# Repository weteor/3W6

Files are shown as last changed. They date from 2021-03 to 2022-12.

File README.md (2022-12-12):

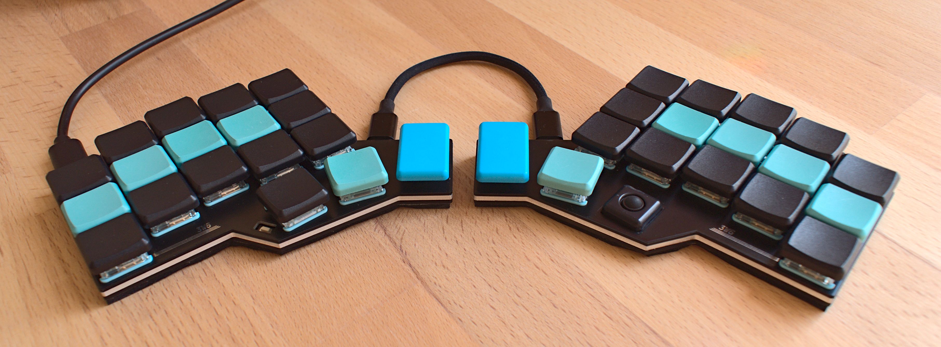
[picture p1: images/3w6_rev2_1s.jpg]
 

# 3w6 - split ortholinear keyboard

The 3w6 is a low profile, split ortholinear keyboard with 36 keys.

I needed a keyboard for work and wasn't really satisfied with the available alternatives (namely Corne, Kyria and Ferris), mostly because they were rather large and didn't had the spacing I would like.

It's designed to be a no frills, cheap and small keyboard to be taken everywhere.

So no hotswap, no multiple switchtypes, no encoders, no LEDs.

BUT with onboard controllers (so no extra ProMicros, Elite-C), production files including SMT assembly files, and sturdy through hole mounted USB-C connectors.
## revision 2.2
changes:
- combi footprint to be able to use the AU or MU variant of the AtMega32U4. 
- add BOM files for each AU and MU variant, so you can choose the cheaper one.
## revision 2
changes:
- new middle plate (1.6mm, better 2.0mm) instead of diodes. Uses Aluminium PCBs as a cheaper alternative to lasered aluminium. 
- pimoroni trackball support (can only be used combined with the new middle plate when used with the plate)
- plate is now 1.2mm thick, to fit the chocs better. Needs middle plate, since the cutouts of the USB-Connectors were left out. There is enough space for them under the plate, when the middle plate is in place.
- added mounting holes to support tenting puck from splitkb.com. Due to insufficient space not all 4 holes are supported, but 3 screws should be enough to hold everything comfortably in position. Can only be used plateless! 
- package for the MCU was changed from QFN44 to TQFP44, since the previous one wasn't available. Can now be soldered/replaced by hand if need.
- IO-expander was changed from TCA9555RTWR to TCA9555PWR (alternativly PCA9555PW), since the previous one wasn't available. Package changed from WQFN24 to TSSOP24. Can now be soldered/replaced by hand if need.
- Board can now be soldered by hand if needed (challenging though, 0402 components). 

## try it
You may also compare the layout with other layouts of other layouts at https://jhelvy.shinyapps.io/splitkbcompare/ .

Or you can print [this file](https://raw.githubusercontent.com/weteor/3W6/main/plate_outline.pdf) to test if you like the layout. Or mount it to some cardboard and test it with your favourite switches.

## production files
If you want to build one yourself, grab the 
Gerber files [here](https://github.com/weteor/3W6/tree/main/prod/Rev2) and give it a go.

And if 3d printing is your thing, files for plate and midlayer can be found [here](https://github.com/weteor/3W6/tree/main/prod/Rev2/3d%20Print) (made by the great [bomtarnes](https://github.com/keyboard-magpie), thanks a lot!)
## build instructions
you may find instructions here: 
- rev1 (deprecated): [build instructions rev1](./prod/build_instruction_rev1.md)
- **rev2 (current)**   : [build instructions rev2](./prod/build_instruction_rev2.md)

## firmware
This keyboard uses [QMK firmware](https://qmk.fm/).
You can find everything you need to build a firmware for this board in the [QMK Repository](https://github.com/qmk/qmk_firmware). 

Here are some instructions on how to [set up your QMK environment](https://docs.qmk.fm/#/newbs) and a few notes [specifically for the 3w6](https://github.com/qmk/qmk_firmware/tree/master/keyboards/3w6).

## the rest
Everything in this repository is free to use however you might see fit. If you want to support me and my projects, please consider linking back to this repository if you build/change/use anything. 

If you would like to send me a tip, you could do it [here](https://ko-fi.com/weteor) (Please don't feel like you have to).

## rev2(current)
3w6 
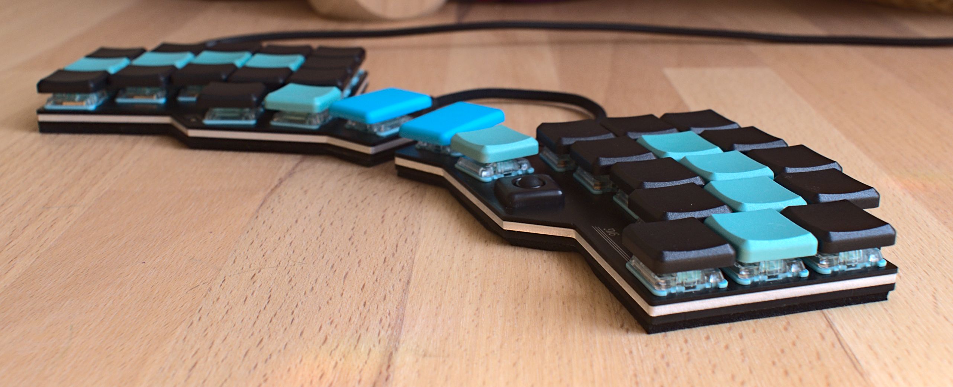
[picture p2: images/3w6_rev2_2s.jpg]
 
## rev1
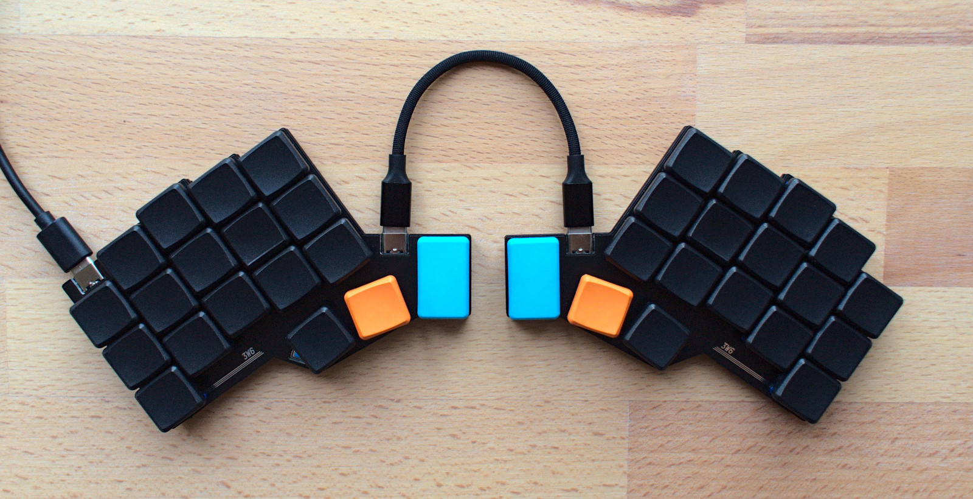
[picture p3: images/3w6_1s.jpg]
 
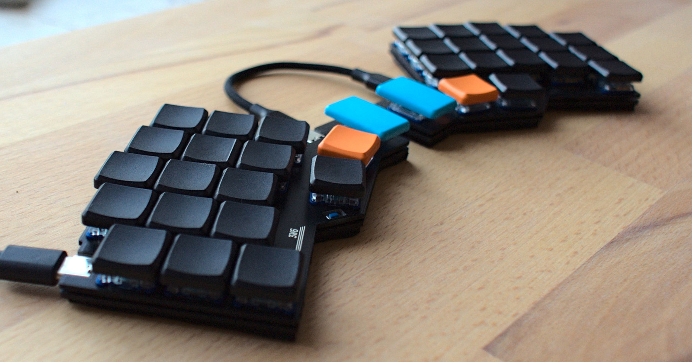
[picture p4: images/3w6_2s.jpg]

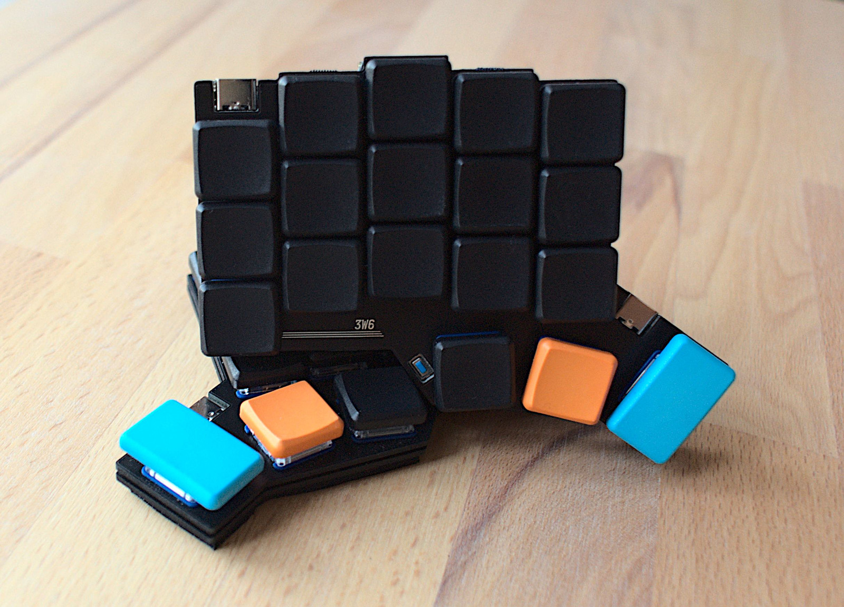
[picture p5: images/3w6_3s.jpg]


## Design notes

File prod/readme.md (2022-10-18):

# Build Guides
- [Build instructions for Rev1](./build_instruction_rev1.md) **outdated design**
- [Build instructinos for Rev2](./build_instruction_rev2.md)
- [Build instructions for Pimoroni on Rev2](./build_instruction_rev2_pimoroni.md)

# Production files
## Rev2 (current)
### Gerber

Prepared for JLCPCB, can be used everywhere, but BOM and placement files might be needing some adjustments)

| Component | Files | Description |
|---|---|---|
| PCB | 3W6_Pcb_Gerber_20221018.zip | Gerber PCB |
| -"- | 3W6_Pcb_PositionTop_20221018.csv | Position File for top Layer ( all smt components are on the top layer ) |
| -"- | 3W6_Pcb_BOM_20221018.csv | Bill of Materials w/ AtMega32U4-AU |
| -"- | 3W6_Pcb_BOM_20221018.csv | Bill of Materials |
| Mid Layer | 3W6_Middle_R_Gerber_20221018.zip | Gerber Middle Plate Right Half |
| -"- | 3W6_Middle_L_Gerber_20221018.zip | Gerber Middle Plate Left Half |
| Switch Plate | 3W6_Plate_Gerber_20221018.zip | Gerber Switch Plate |

### 3d printing files 
Files for mid layer and switchplate can be [found here](https://github.com/weteor/3W6/tree/main/prod/Rev2/3d%20Print)

Big thanks to [**bomtarnes**](https://github.com/keyboard-magpie) for making these files available

### Rev1 (outdated)

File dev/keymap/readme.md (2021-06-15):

###  Base Layer 

#### Colemak (default)
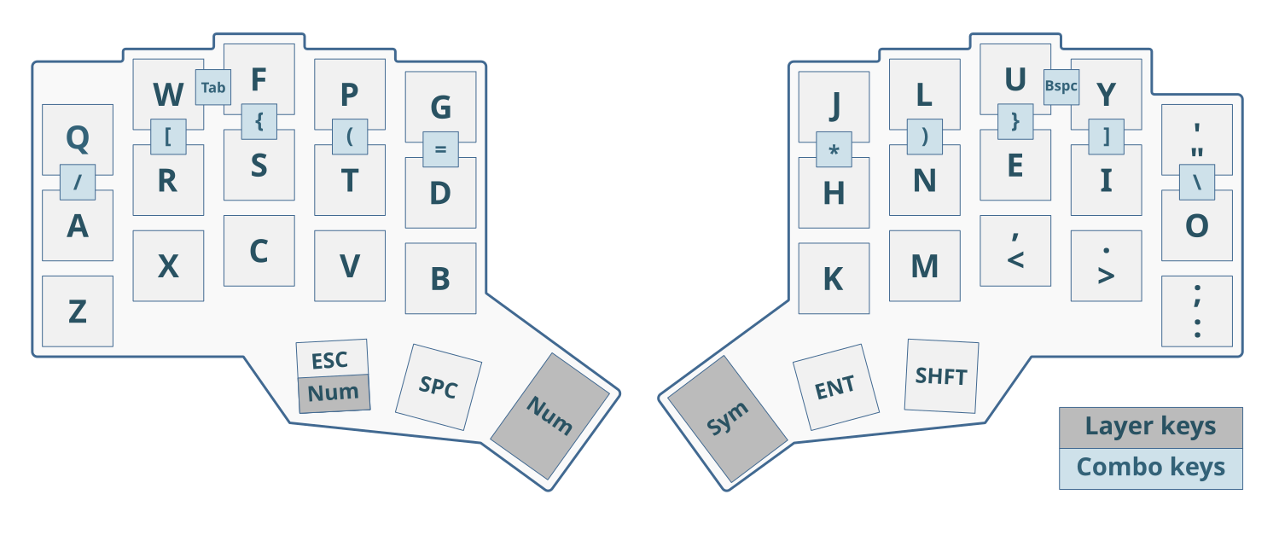
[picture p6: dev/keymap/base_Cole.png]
image colemak


#### Quertz
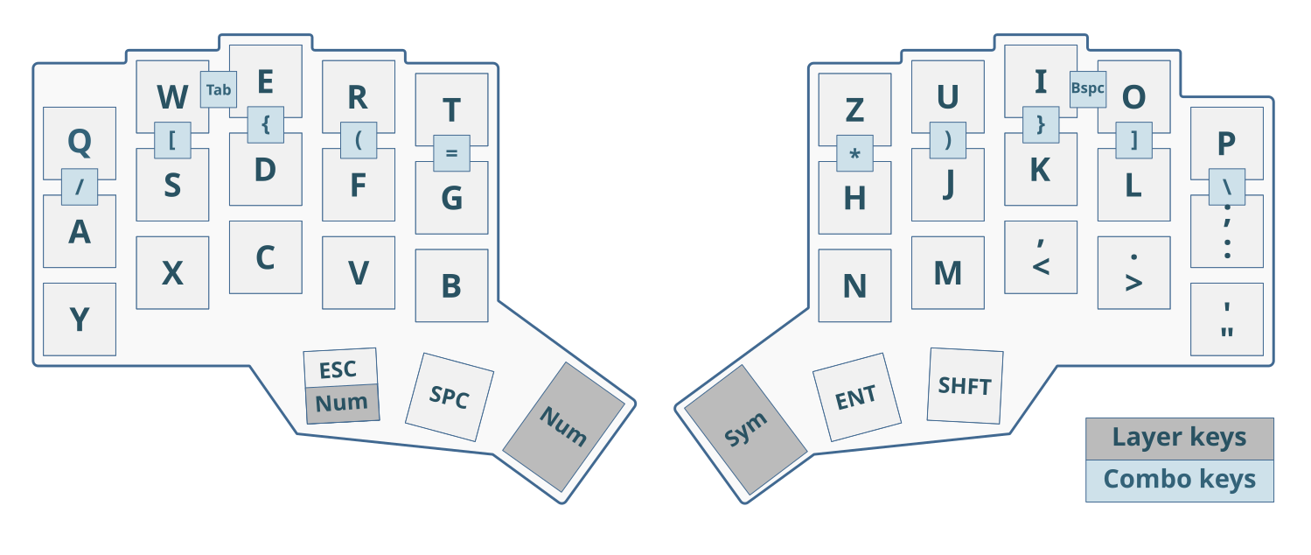
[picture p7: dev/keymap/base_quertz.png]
image quertz


#### Beakl, Colemak DH and Handsdown-Alt accessable through CFG Layer

### Symbol Layer
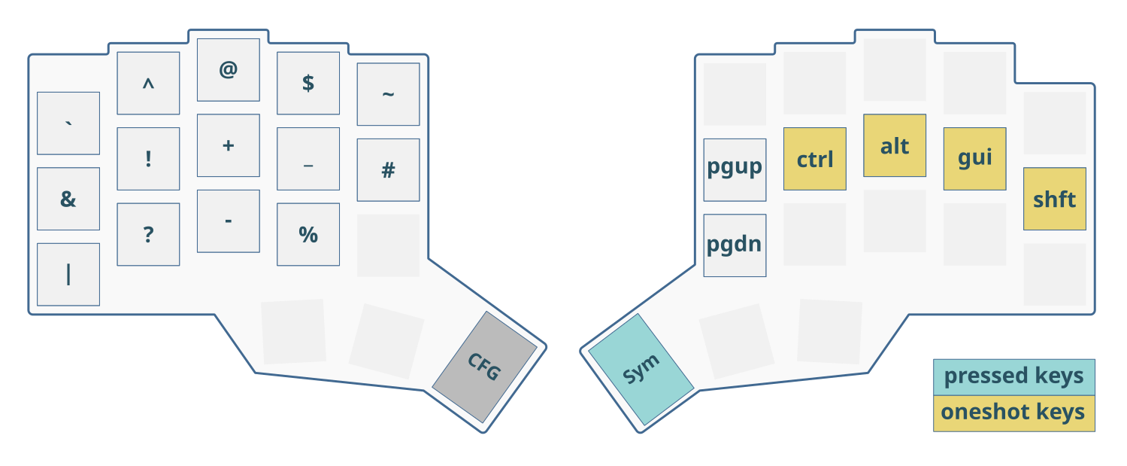
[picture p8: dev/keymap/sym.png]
image sym

 
### Navigation Layer
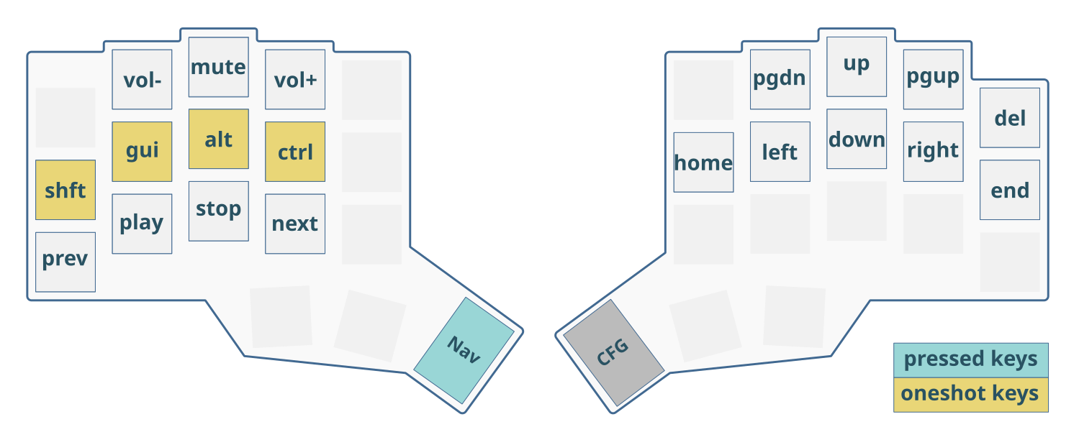
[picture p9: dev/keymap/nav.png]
image nav


### Number Layer
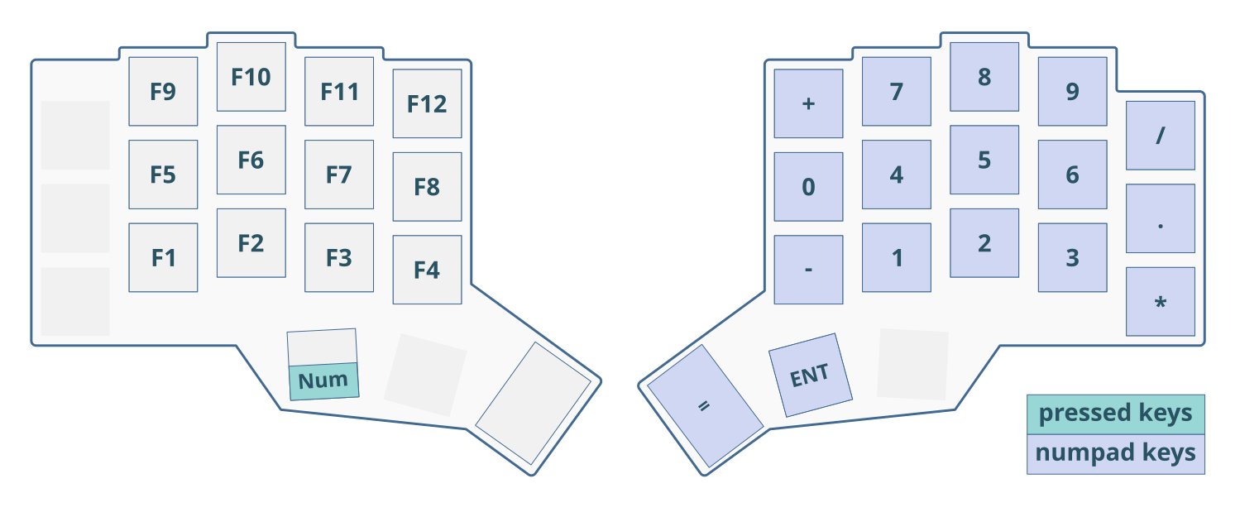
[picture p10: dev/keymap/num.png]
image num


### Config Layer
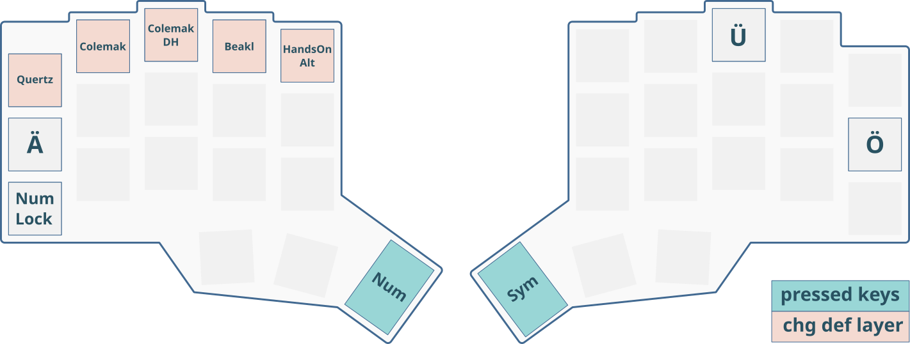
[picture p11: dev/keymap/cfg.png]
image cfg


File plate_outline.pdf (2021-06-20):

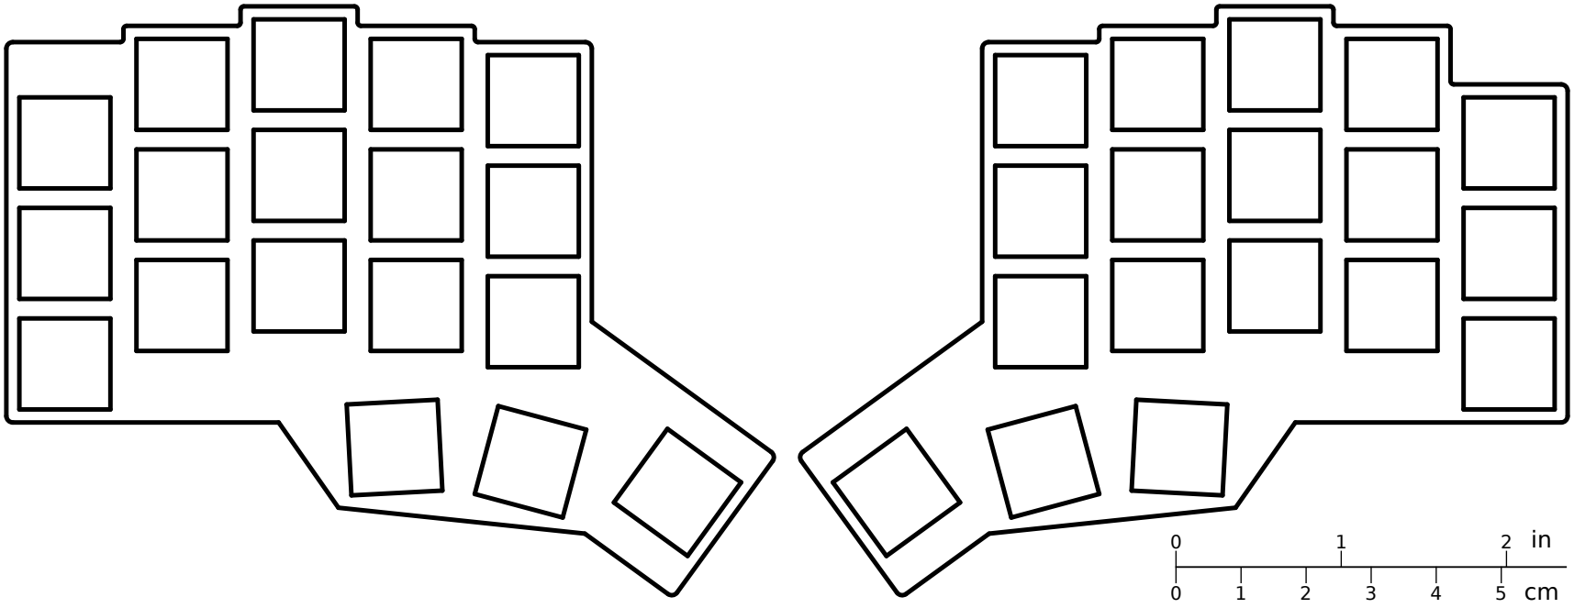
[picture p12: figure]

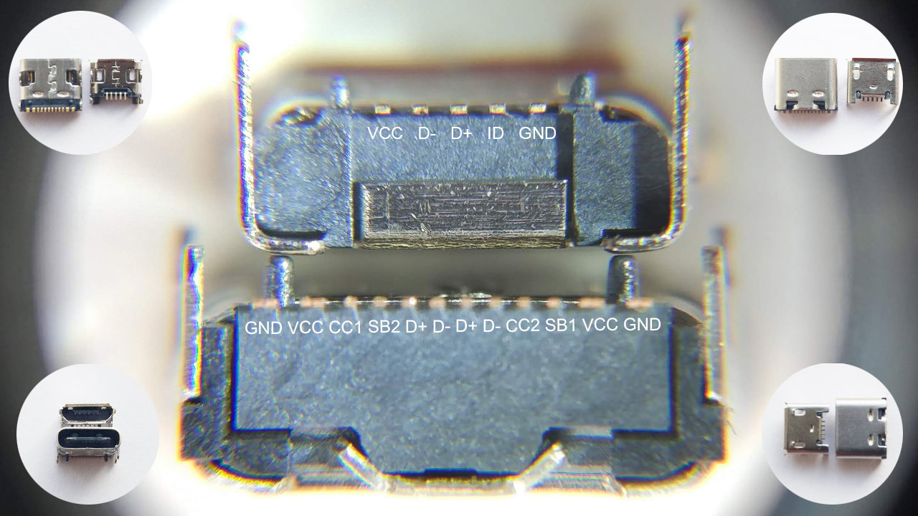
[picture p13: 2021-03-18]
dev/docs/USBC_12pin_Pinout.png

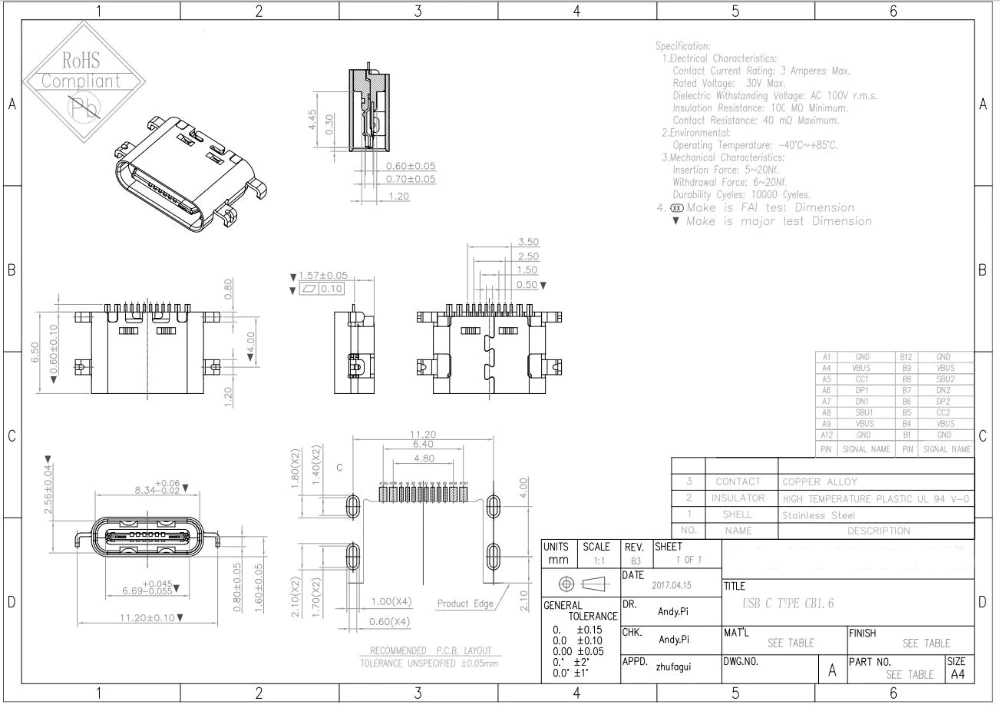
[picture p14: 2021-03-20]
dev/docs/USBC_12pin_DataSheet.png

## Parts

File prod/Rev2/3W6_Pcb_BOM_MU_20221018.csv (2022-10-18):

Comment | Designator | Footprint | LCSC
22pF | C1,C2 | Weteor:C_0402_HandSolder | C1555
0.1uF | C3,C4,C5,C6,C7 | Weteor:C_0402_HandSolder | C1525
4.7uF | C8 | Weteor:C_0402_HandSolder | C23733
1uF | C9 | Weteor:C_0402_HandSolder | C52923
D | D2,D3,D4,D5,D6,D7,D8,D9,D10,D11,D12,D13,D14,D15,D16,D17,D18,D19,D20,D21,D22,D23,D24,D25,D26,D27,D28,D29,D30,D31,D32,D33,D34,D35,D36,D37,D40,D43,D44,D50,D52 | Weteor:D_SOD-123 | C81598
500mA | F1 | Fuse:Fuse_1206_3216Metric | C106264
USB_C_midMount | J1, J2, J3 | Weteor:USB-C-12-Pin-MidMount | C168688
5.1k | R1,R2 | Weteor:R_0402_HandSolder | C25905
4.7k | R3,R4 | Weteor:R_0402_HandSolder | C25900
22R | R6,R7 | Weteor:R_0402_HandSolder | C25092
10k | R5,R8,R9 | Weteor:R_0402_HandSolder | C25744
ATmega32U4-AU | U1 | Package_QFP:TQFP-44_10x10mm_P0.8mm | C112161
PCA9555PW | U2 | Package_SO:TSSOP-24_4.4x7.8mm_P0.65mm | C128392
16MHZ | Y1 | Crystal:Crystal_SMD_3225-4Pin_3.2x2.5mm | C13738

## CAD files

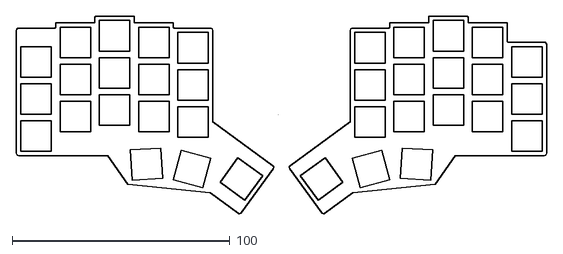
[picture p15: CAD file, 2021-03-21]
dev/Board Shape/OutlinePlate_v1.dxf
243.2 x 90.7

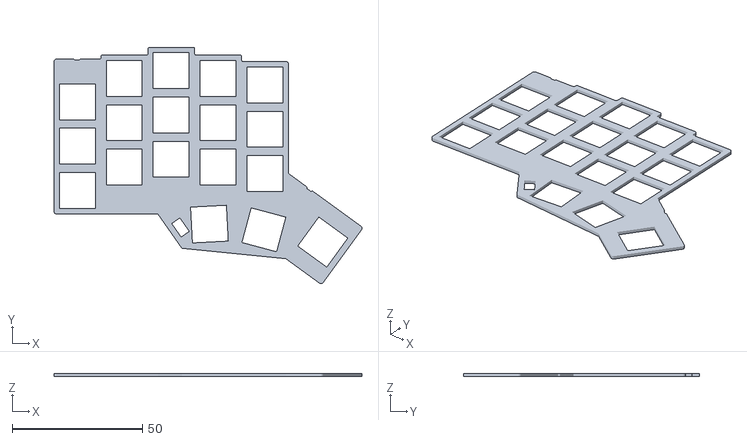
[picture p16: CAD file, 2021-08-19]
prod/Rev2/3d Print/3W6_Plate-left-v2.stl
118.2 x 90.7 x 1.20

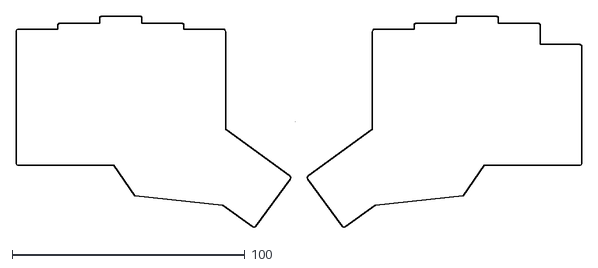
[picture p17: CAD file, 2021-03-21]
dev/Board Shape/Outline_v1.dxf
243.2 x 90.7

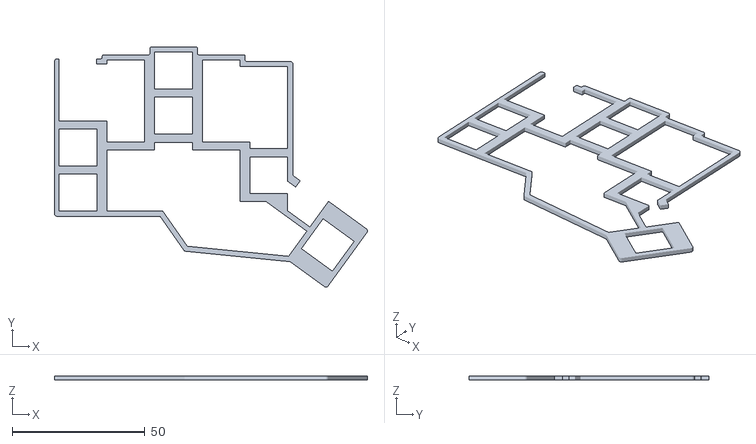
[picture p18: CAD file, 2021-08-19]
prod/Rev2/3d Print/3W6_Plate-middle-left-v2.stl
118.1 x 90.6 x 1.60

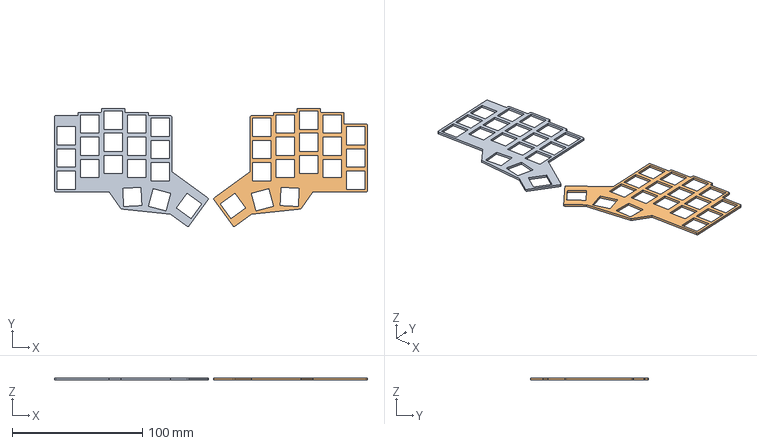
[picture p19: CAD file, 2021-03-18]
dev/Board Shape/Outline.FCStd
240.0 x 90.6 x 1.60 mm
Left Half
Pad001 (Mirror #1)

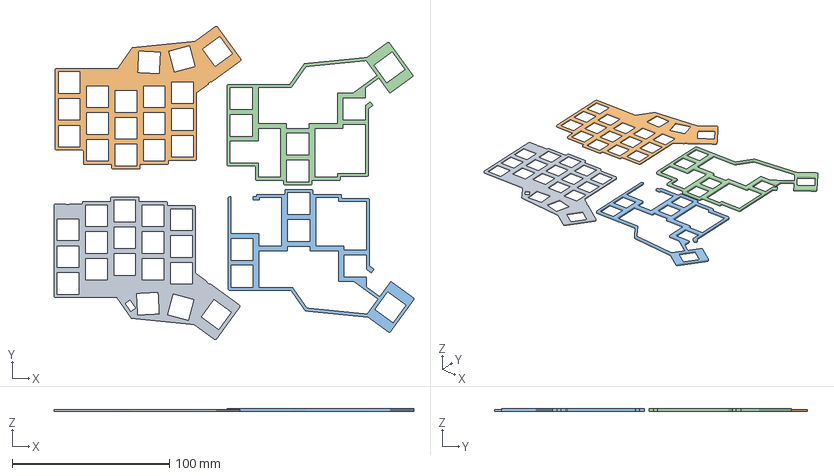
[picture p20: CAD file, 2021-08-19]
prod/Rev2/3d Print/3w6-prusa-plate-v2.3mf
228.7 x 199.1 x 1.60 mm
3W6_Plate-left-v2.stl
3W6_Plate-right-v2.stl
3W6_Plate-middle-left-v2.stl
3W6_Plate-middle-right-v2.stl

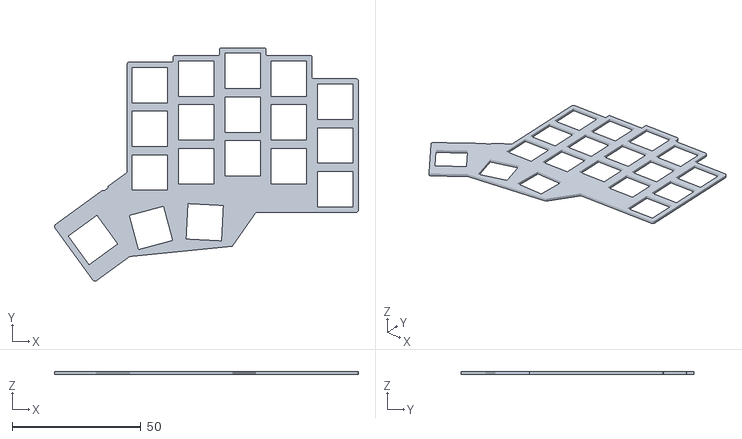
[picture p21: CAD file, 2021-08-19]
prod/Rev2/3d Print/3W6_Plate-right-v2.stl
118.2 x 90.7 x 1.20

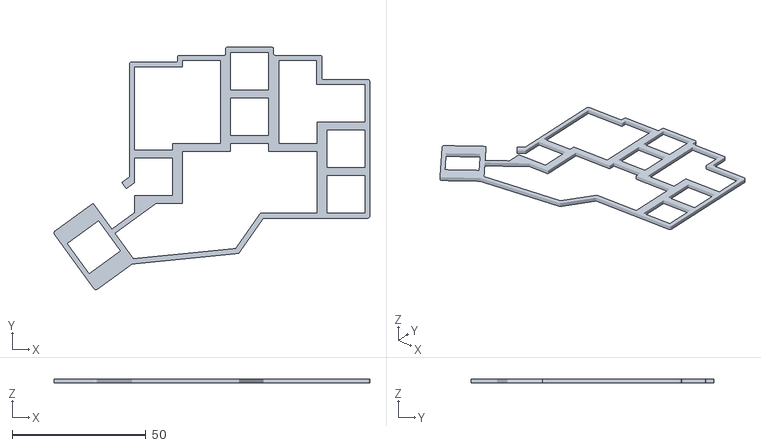
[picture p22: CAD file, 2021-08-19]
prod/Rev2/3d Print/3W6_Plate-middle-right-v2.stl
118.1 x 90.6 x 1.60

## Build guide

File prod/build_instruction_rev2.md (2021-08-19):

**if you are going to order pcb with the provided files please make sure the components in the BOM are still valid and have the correct values! I will update them from time to time, but there is no guarantee the current version is still correct.**

If the board was manufactured with the included Bom and Pick and Place Files the following components are needed to complete the build:

Amount | Component
-------|----------
1        | 3x6x2.5mm SMD Micro Switch, can be found on Ebay or Aliexpress
36       | Kailh Choc V1 switches
34       | Keycaps 1u, 17x18mm, Kailh original choc caps work, transparent ones might not. MKB fit perfectly
2        | Keycaps 1.5u, same as above exept size obviously
1        | USB-C to USB-A cable (connection to PC)
1        | USB-C to USB-C cable (connection between halves)
optional | [Pimoroni Trackball Breakout](https://shop.pimoroni.com/products/trackball-breakout)
optional | [Tenting Puck](https://splitkb.com/products/tenting-puck)
optional | some self adhesive neopren material to put under the board, *alternativly* some rubber feet
optional | black permanent marker to paint the edges of the PCB

optional step:
- use a black (or whatever color matches your board) permanent marker to paint all edges. I think it looks a lot nicer with darker edges.

ok, let's start:
- solder the microswitch. Start with one side and check if the plate will fit before soldering the other side.
- connect the left half ( the one with two USB connectors) to the PC and try to flash the board. 
- Open some kind of editor and check if the board is working by shorting the two slots for each switch on the bottom of the pcb (use a paperclip or tweezers). If single switches don't work check and/or change the matching diode.
- connect both sides and check the same way. ( you can safely connect the sides while the board is connected to the pc)

optional step:
- solder the pimoroni trackball to the pcb. [See instructions here](./build_instruction_rev2_pimoroni.md)

ok, ready to put the switches on.

- start with the six switches which are completely surrounded by the midlayer. Clip them in the plate and solder them to the pcb. If unsure solder just one leg, that way it is easier to correct mistakes. Make sure the middle plate is tightly squeezed between plate and pcb. If you use a 2mm midplate, it is normal that the switch pins are only barely visible on the back of the pcb.
- clip in a few more switches and solder them as above.
- rinse & repeat

optional step:
- cut the neopren to fit the board and tack it under it, or use some rubber feet. 

Congratulations, you should have a functioning and nice looking keyboard now!

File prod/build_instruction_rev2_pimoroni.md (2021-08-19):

**Build instructions for Pimoroni Trackball**

First we need to fit the trackball in the plate. The cutout is a tad too small to fit for the pimoroni to fit well with the choc switches.
Try to fit the trackball and use a file to widen the cutout untill the housing fits. File the edge nearest to the alpha keys.

Clip the six switches which are surrounded by the midplate into the plate.

Now we need to remove some parts of the pimoroni PCB ... don't panic, everything will be fine.
File away until the corner between the "5VOK" and "ADDR+1" print. 
This is how the result should look like:

Put the Pimoroni into the plate and try to fit it together with the midplate. The midplate should without being pushed out by the pimoroni pcb. If not, file a bit more until it fits.

ok, now take a look at the bottom of the pcb and see how the vias align between pcb and Pimoroni. There will be an overlap, thats ok. 
Solder some wire to each via on the Pimoroni. Try to keep the wire more to the edge. Try to fit the wires in a way that there is minimal wire or solder to the side where the plate will sit.

Again, fit the pimoroni in the plate. Use plate, switches and midplate to get a proper alignment and fit the wires through the pcb.

Solder and clip.

*if you use a Rev 2.0 board* (see back of pcb ner the inner thumbkey).
There is an error on the board. The Pomoroni GND PIN is not connected to the boards GND. Two options.

1. Solder a wire to the gnd pin. Feed it through the big hole next to the pimoroni and the IO Expander (the big chip) and solder the wire to the pins marked x (or look into the schematic to see which pins are gnd)
```
   | | | | | | | | | | | |
   | | | | | | | | | | | |
   -----------------------
  |                       |
  |       TCA9555         |
  |       TSSOP-24        |
   ------------------------
   | x x | | | | | | | | |
   | x x | | | | | | | | |
   
```
2. scrap away a bit of soldermask on the back of the board, the copperlayer there is Gnd. Either bridge with solder or use some wire to connect Pin with the copper.

Congratulations. Pimoroni installed!

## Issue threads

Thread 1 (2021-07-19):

Interested in getting one V2

llpamies, 2021-07-19:
I was trying to see if JLCPCB could make one, but they run out of TCA9535PWR...
Have you managed to order some V2? I am interested in buying a couple for myself. Thanks!

weteor, 2021-07-20:
Yeah, having all parts available is a problem right now. Changed the footprints of the IOExpander and the MUC because of that.
If you feel confident soldering and are able to source the TCA9535PWR from elsewhere, you could leave it out of the assembly and solder it on by yourself later.
If you don't want that, I have ordered a batch of 3W6 V2 and theoretically I still have 3 left over, so you can get one from me as well.
I will have to check the boards though. Last time I had a few duds and I must be sure  to have enough functioning boards. If you are interested let.me know and I come back to you, when I know how many boards I have left.

weteor, 2021-07-20:
Ok, so I messed up.

The TCA9535PWR isn't working. It has to be the TCA9555PWR. Same Chip, but the 9535 does not have  internal pullup resistors, which I missed when I swapped the chips. So the right half will not work.
Pinout is the same, you only need to change the Chip and JLCPCB Part number in the BOM File.
If the TI Version isn't available you could use the NXP PCA9555 which seems to be the same chip and it looks like it is in stock at JLCPCB at the moment.

llpamies, 2021-08-06:
Thanks. I have finally ordered 5 of the v2.1 They didn't have the microcontroller in stock, which I will have to solder manually. I only got PCBs, since I am planning to 3d print plates and case. If the boards work, I could sell 3 of them if anyone is interested.

weteor, 2021-08-15:
great, let me know if everything worked out

llpamies, 2021-08-19:
The build went perfect. Some notes:

- JLCPCB didn't have the MCU, so I had to desolder if from a Pro Micro I had lying around (with a big hot air gun).
- I didn't use the PCB plates in your production files, but I designed a single top-middle plate combo on onshape, and 3d printed it: https://tinyurl.com/w6n2rknr (you can export .stl via export, when you right click on the part list).
- I used sticky neoprene adhesive for the bottom plate.

Some pics (waiting on a shorter usb-c cable): https://photos.app.goo.gl/o8Fyw2KQMJSpyTG76

Thank you so much for sharing the design!!! It is the perfect keyboard for me!

Do you mind if I share the pics on r/ErgoMechKeyboards and link to your github?

weteor, 2021-08-19:
That's so great to hear.

Those boards look great, thanks for sharing the pics. And sure post/share wherever you like.

Yeah the MCU is a gamble. They are regularly oos. At least with v2 there is the possibility to solder them on yourself :)
I use the same sticky neoprene, its really nice. Everything stays where it belongs.

Hope you'll enjoy using the keyboard!

Closed 2021-08-15.

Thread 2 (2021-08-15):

Alternative MCU Packages

peterlok27, 2021-08-15:
Hi! Thank you for your effort. I love the design idea. Can I just ask whether the QFN-44 is compatible with the PCB? TQFN-44 is rather hard to find where I'm at :((

weteor, 2021-08-15:
Hi

unfortunately the QFN-44 is not compatible with Rev2. It hat to be the TQFP package.

I've just checked and LCSC has them in stock and they deliver almost everywhere. Maybe that is an option?

You may also check Octoparts, which lists stock on a multitude of sites, maybe you can find something there:
https://octopart.com/search?q=atmega32u4-au&currency=USD&specs=0

Closed 2021-08-24.

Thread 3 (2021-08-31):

Planning on ordering from JLCPCB, need some guidance

coniel, 2021-08-31:
First of all, thanks for the great work. The keyboard looks excellent. I've never ordered a PCB before so I was hopping to get some assistance.

JLCPCB seems to be out of three components:
- TCA9555PWR (they don't have NXP PCA9555PW either)
- ATMEGA32U4-AU
- 500mA fuse

I Think that I should be able to source and solder the TCA9555PWR and ATMEGA32U4-AU. I'm just wondering about the fuse, should be easy enough to find, but it looks tiny and I'm not sure I'd be able to solder it. Is there another model I could replace it with on JLCPCB?

I also have a few questions regarding the order process itself:
1. The SMT assembly should be on top, right?
2. On the Upload BOM/CPL screen, should I upload `3W6_Pcb_PositionTop_20210728.csv` as the CPL file?
3. The middle and plate should use aluminium as the base layer, right?
4. For the middle boards, it's asking for their dimensions. I'm not sure what to enter for that.

Sorry for asking so many trivial questions. It's my first time building something like this, so I'd rather ask then mess it up over something silly.

I'd be happy to send you some beer money if you've got somewhere that I can send it to!

weteor, 2021-08-31:
Hi, thanks for building the board :)

If you've soldered something before, you should be able to get the atmega and tca on the board. The fuse is rather large in smd terms and could easily be soldered by hand, but you can exchange the one from the BOM with Part No C135336. Should work fine.

Regarding your questions:
1. yes, all smd assembly takes place on the top layer.
2. yes
3. both is preference really. I like the plate i little less stiff and prefer FR4 to aluminium.  The middle layer is optional. I like to have it for aesthetic reasons, the whole base is closed and it looks a bit more finished. Well and its a bit easier to get constant offset between Pcb and plate.
I used aluminium because I liked the look of that stripe of metal in contrast to the black plate and pcb. But it's equally fine to use FR4 for the mid layer as well.
Important is that the Switchplate is 1.2mm thick so the choc switches clip in properly. Mid layer, if used, should have 1.6mm or 2mm. With less the Usb connectors won't fit well, and with more you won't be able to solder the switches.
4. dimensions should be 118mm * 92mm .

JLC can be a bit iffy sometimes, depending who reviews the files.
- The switchplate may cost an additional fee because of all the cutouts, nothing you can really do if it hits you.
- They might say that the board can't be made because the slot to slot and slot to board edge is too small. If that happens just contact them via chat and tell them, that you are sure its fine and you wish to proceed on your own risk. Normally they will do that, and it will be fine.

-Similarly they had totally unrealistic demands of 6mm edge to edge with the aluplates, which I couldn't resolve. I had to order them elsewhere. But I think they loosened up the restrictions in the meantime. Again try to proceed on your own risk. The design is fine to produce as it is.

Hope that helps, let me know if there is anything else I can help with

weteor, 2021-08-31:
Oh and one last thing. I am going to get another run of boards made in two or three weeks. So if you are want you could get a kit form me in the future.
But making it for yourself is certainly the more exciting (and faster) option!

coniel, 2021-09-01:
Thanks for the quick reply and additional details!

I'd like to get it as soon as possible so I'll have a go at ordering it myself.

Out of curiosity, what's the configuration of the keyboard in the readme pictures? Is the plate made of black FR4 or is it aluminium?

weteor, 2021-09-01:
Cool, let me know how they turn out!

The board in the readme has 1.2mm FR4 Plate, 2mm Alu mids, 1.6mm FR4 PCB with 2mm self adhesive Neopren underneath.

Plate and PCB are with black soldermask and I painted the edges with a black permanent marker before assembling. Normally the edges are much lighter colored which doesn:t look as nice.

coniel, 2021-09-02:
Cool, thanks!

I was playing around with the JLCPCB panel settings and it looks like black FR4 is $49.38, whereas the same settings on an aluminium plate is only $14.00. Was that the case for you?

weteor, 2021-09-02:
Ah, that's because of the special processing fee.
 I assume JLC detects a one layer board rom the gerber files and 1.2mm, 1 layer boards with black solder mask are rather rare, so they charge extra.
Try setting layers manually to 2 and the price should drop significantly.

coniel, 2021-09-02:
Oh yes, that did it. Thanks a lot!

LandingEllipse, 2021-09-15:
> Oh and one last thing. I am going to get another run of boards made in two or three weeks. So if you are want you could also get a kit from me (mid to end October they would be ready I think).
> But making it for yourself is certainly the more exciting (and faster) option!

Sorry to hijack this, but I'd be very interested in buying a kit from you if that's still on the table. If it is (or if there's another opportunity in the not too distant future - my Kyria is alive and well so I'm not in a massive hurry), please let me know your preferred communications channel / how to proceed.

Cheers!

555wolfman, 2021-09-22:
@weteor #metoo
I am also interested in buying 2 kits.

thanks in advance

Olaf

555wolfman, 2021-09-27:
BTW: there are more vendors on the market who offer an assembly service. Elecrow, PCBway, JLCPCB.
From PCBway i have heard that they order your parts for you or you can provide some parts that are difficult to get.
Due to i‘ve newer done such an order i do have much respect. I don’t know if providing gerber files and BOM is enough or if they need additional info, like aligning/turning some components the right way.

555wolfman, 2021-09-27:
> Ah, that's because of the special processing fee.
> I assume JLC detects a one layer board rom the gerber files and 1.2mm, 1 layer boards with black solder mask are rather rare, so they charge extra.
> Try setting layers manually to 2 and the price should drop significantly.

@weteor  is your pcb order on the way or is it possible to add some more kits?

please contact me at discord 555wolfman#9345

thanks

weteor, 2021-09-29:
@LandingEllipse, @555wolfman

sorry for the late reply.

I don't have any kits left unfortunately.  I may make another run in the future, but this will be more than a few weeks away, because currently I don't have time to do it.

With a bit of luck a batch of kits might become available from an online seller in the nearer future, but that's not fixed either. Will link to it should it happen.

> BTW: there are more vendors on the market who offer an assembly service. Elecrow, PCBway, JLCPCB.
From PCBway i have heard that they order your parts for you or you can provide some parts that are difficult to get.
Due to i‘ve newer done such an order i do have much respect. I don’t know if providing gerber files and BOM is enough or if they need additional info, like aligning/turning some components the right way.
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
Confuset, 2022-08-02:
I don't think that it will fit. If you look at the datasheets you will see that the C168688 has "wings" to connect them to the PCB, while C2927037 does not..
I am currently searching for a compatible connector, but not was not yet successful.

sam-d, 2023-02-18:
I also have issues with the USB-C parts. While they are currently in stock at JLCPCB, they are only compatible with standard PCB ( not the economic one) and actually *double* the price of the PCBs. What would be the impact of using topmount (instead of mid-mount) USB-C ports? In my case I plan on 3D printing the plates etc. so can make small changes there. It would be great if @weteor could provide some insights (and ideally some other compatible part numbers).

weteor, 2023-02-20:
@sam-d sorry for the late reply.

Yeah JLC introduced the different tiers of assembly recently.

Top mount USB Ports are not ideal, because they would stick out of the top plate. The USB footprint would have to be changed, too, since top mount and midmount don't use the same footprint. If that doesn't bother you, you certainly could change the footprint to top mount and add an opening in the switchplate.

Another option would be to simply remove the USB Connector from the Assembly, order some 16pin mid mount USB-C connectors from Aliexpress/Mouser/etc. (they are dirt cheap) and solder them yourself. That's what I am doing currently.
Those aren't too hard to solder if you have some flux at hand.

eallenwright, 2023-08-15:
Hey @weteor. Sorry to revive such an old thread. I am ordering from JLPCB, specifically stuck on the top plate. The configuration of 1.2mm, black, and lead-free HASL is causing the $16 special processing fee. If I remove lead-free HASL, the fee is removed. If I use 1.6mm PCB, the fee is removed. I was wondering if the coating is even applied to the top plate? I don't want to be touching lead, which is why I selected lead-free. But from what I understand, there are no copper components on this top plate anyway that would need coating. So... should I just select HASL with lead because it will be cheaper (and not even applied)?

Thanks a lot.

weteor, 2023-08-15:
Hi, yeah any 'special' combination with the 1.2mm plate might increase the price. Keeping the 1.2mm plate thickness  is recommended  for the switches to clip into the plante correctly.

The writing on the top plate will geht covered with the leader paste. I personally doubt that there is any adverse effect during normal use.

But if it bothers you, you may either remove the print from the top and bottom soldermask layers or move them from there to the top/bottom silkscreen layers.

eallenwright, 2023-08-16:
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

Thanks a lot for this information!

eallenwright, 2023-08-16:
Thanks a lot for the above reply. One more thing…

I placed my order. Got hit with the fee for cutting out the plates. Ouch, but I guess that’s that. They did complain about both the middle plate edge width and the slot to slot/slot to board edge being too thin on the top plate. No surprise, and they seem fine accepting it.

However I got hit with another charge pertaining to the main board pcb:
“ The order info shows that there is only one design , but actually, there are 2 different designs in your file, so there will be an extra cost for it if you want to make it as show in your file.Please kindly choose the correct designs when you place your order next time.”

I’m not sure what I did wrong here. I uploaded the Gerber file and went through the processes of instructing them to assemble the top layer. Did the Bom and Pick and Place portion (sans usb c connectors) and added it to my cart. I’m wondering if this is something they have wrong or if I indeed neglected to add the proper design.

Thank you!

eallenwright, 2023-08-16:
I just wanted to follow up on my above question, as it's probably better suited for JLCPCB support rather than here. I reached out to them and they explained it. But in case someone had a similar issue: You need to select that there are two designs when you upload the Gerber files for the main board and for the top plate. If you don't, you will be charged a difference later. It seems that this charge sometimes gets missed by their reviewers, which is why some people get charged and some people do not. In my case the reviewer noticed that the top plate and main board have two sides, and they consider these two designs each, which incurs ~$10 in extra fees for both parts.

Closed 2024-04-30.

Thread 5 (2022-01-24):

Alternative diodes to 1N4148W

KYTAZ0, 2022-01-24:
Hello, I would like to order some pcbs from jlcpcb but they're lacking this component other than the microcontroller.

While I'm positive I can figure out how to get the microcontroller soldered somehow not being able to order the rest of the board assembled really stops me at this point. I happen to have no experience with ordering a pcb or building a custom keyboard so I'm a bit too much on the newbie side in order to take my chances and look for alternative suppliers or pick the component myself.

Any bits of help would be appreciated

weteor, 2022-01-24:
Hi,
you can replace it with part no C2099. You should be able to search for it in the screen, where it says the part is not available. Or replace it in the BOM file. Hope everything works out and thanks for building!

KYTAZ0, 2022-01-24:
No thank you, you're the man

Closed 2022-01-24.

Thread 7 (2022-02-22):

Alternative microcontrollers? ATMEGA32U4-AU is hard to find

tqmai, 2022-02-22:
Hi there, thanks again for creating this awesome keyboard! Very excited to build this and try it out.

I've been having trouble sourcing ATMEGA32U4-AU microcontrollers - I've had two orders fall through already. Do you know of any alternative microcontrollers that would work for this board?

BenRoe, 2022-10-18:
Last commit added support for ATMEGA32U4-AU and ATMEGA32U4-MU.
So issue can be #close

weteor, 2022-10-18:
right. I've changed the footprint to support both the AU and MU variant. So it's possible to choose the one which is cheaper

Closed 2022-10-18.

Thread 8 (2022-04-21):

[Feature Request] NiceNano Version / Bluetooth

jaddel, 2022-04-21:
Hi, thanks for sharing this great project with us!

Could you imagine to do a PCB template that has a niceNano or some other integrated Bluetooth module? I personally wouldn't mind to have the halves still connected via a wire as long I could ride of the main cable...

weteor, 2022-04-26:
it's something I am thinking about, but haven't had the time to do. Nice Nano or other BT Modules are out of the question unfortunately, because they are simply too large. On Board Chip is the way to go, but that is quite a bit of work ... and finding a place for the batterz is challenging too.

tl;dr I have plans, but I don't think it will happen in the next few month

Closed 2022-04-26.

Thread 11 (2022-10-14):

How do i order the pcb

Infinitybeond1, 2022-10-14:
**Hey I love this keyboard and how it looks. Great job on designing it!**

I want to order the pcb for this keeb off of jlc and i was quite confused on how to do it. Like do i just drop the gerber files on jlcbcb? Or do i have to do something else too. I want it ordered so that the micro controller is already soldered on.

Infinitybeond1, 2022-10-14:
Does the pcb itself cost 200 dollars or did I do something wrong

weteor, 2022-10-18:
Hi, sorry for the late reply. Looked into this.

The AU variant of the MCU was quite constly with 19 USD. JLC also changed their assembly and now offers economic and standard pcba. Unfortunately the USB connectors require standard level.

I've just added new pcb data, so you can choose which Variant of the MCU you can use. The MU Variant costs only around  4 USD, so that should move down the costs quite significantly. If you feel comfortable soldering, you could costs quite a bit by not letting JLC solder the USB connectors and do it yourself.

Then 5 assembled Pcbs should cost around 65 USD.

Hope that helps.

Infinitybeond1, 2022-10-22:
Oh yea thx

Infinitybeond1, 2022-10-22:
I really do love how this board looks

Closed 2024-04-30.

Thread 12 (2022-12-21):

Can't get into bootloader

idank, 2022-12-21:
Hey, I got the v2 board assembled at jlcpcb, and did the MCU soldering by hand (they didn't have it in stock). I got the AU atmega, specifically this one: https://www.aliexpress.com/item/32597714506.html.

Connecting it and pressing the reset button doesn't seem to get me into the bootloader. I have QMK toolbox open and it doesn't show anything connected.

The obvious thing to check is the soldering I did on the MCU, so I checked all the pin connections on it (probing the top of pin on the MCU) and it seems they're all connected to their respective pins. Also checked voltage across GND and 5v on the MCU and I'm getting 5v when the USB is connected. Here's an album showing the board: https://photos.app.goo.gl/LQvmafck5J4vCPHB6.

Is there anything else I can do to troubleshoot this? Thanks!

idank, 2022-12-24:
@weteor

BenRoe, 2022-12-27:
It could be that there are some small shorts on the mcu pins, due to the sprayed solder. Try to reflow it with some flux and clean it with isopropanol.

idank, 2022-12-27:
I'm not sure I actually made things better: https://photos.app.goo.gl/bEHKugojHuBCVpEA8

I don't know what else I can try, it's so frustrating.

BenRoe, 2022-12-27:
The soldering looks not good. It could be the problem, but i can be wrong. Sry

Closed 2024-04-30.

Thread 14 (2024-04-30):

JLCPCB asking to confirm Polarity

Koltsz, 2024-04-30:
Hi,

JLCPCB are complaining about polarity with U1, this is what I uploaded:
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

They sent me a DFM with this and asked me to confirm.
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

I am assuming I am OK to continue?

Appreciate all the work that has been done for this keyboard. looking forward to finally getting one.

weteor, 2024-04-30:
I think the it has to be rotated by 90 degrees clockwise. Pin 1 is to the top right, like so:
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

Koltsz, 2024-04-30:
Ahh they did send another one that I found:

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

I guess they did fix it and wanted to confirm

weteor, 2024-04-30:
yes, this looks right to me

Koltsz, 2024-04-30:
Thank you for the quick responce.

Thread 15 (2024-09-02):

SMD1206P050TF/15 not in Stock, can be replaced by SMD1206P050TF/24 ?

Confuset, 2024-09-02:
Hi,
as mentioned in the title SMD1206P050TF/15 is out of stock. Can that FUSE be replaced by SMD1206P050TF/24?

weteor, 2024-09-02:
yes, that should be no problem

Closed 2024-09-02.

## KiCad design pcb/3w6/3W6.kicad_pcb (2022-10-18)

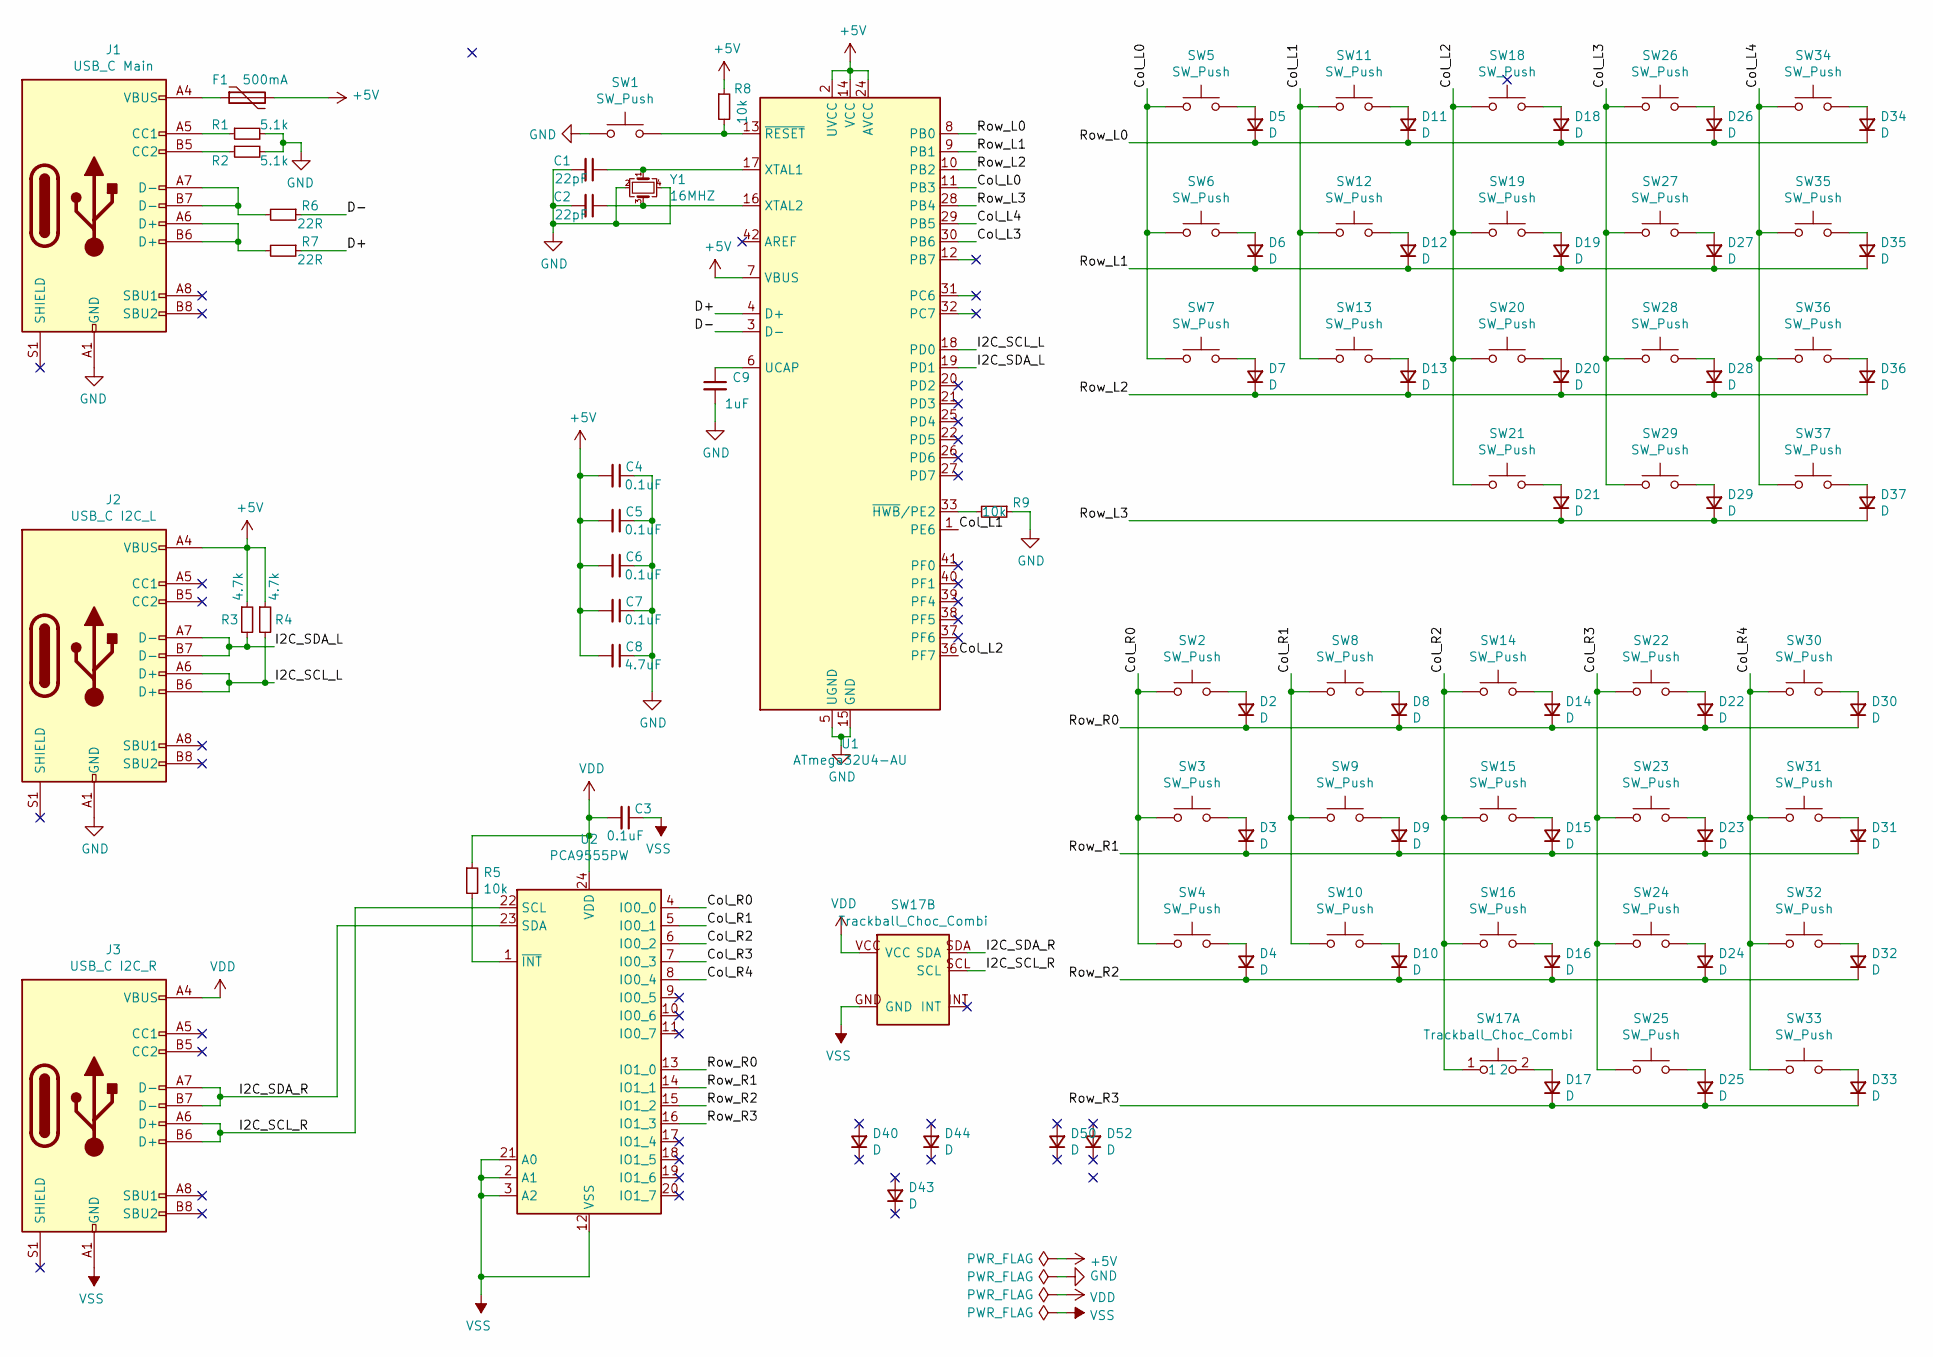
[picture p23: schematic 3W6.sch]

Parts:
C1, C2: 22pF; C_0402_HandSolder
C3, C4, C5, C6, C7: 0.1uF; C_0402_HandSolder
C8: 4.7uF; C_0402_HandSolder
C9: 1uF; C_0402_HandSolder
D2, D3, D4, D5, D6, D7, D8, D9, D10, D11, D12, D13, D14, D15, D16, D17, D18, D19, D20, D21, D22, D23, D24, D25, D26, D27, D28, D29, D30, D31, D32, D33, D34, D35, D36, D37, D40, D43, D44, D50, D52: D; D_SOD-123
F1: 500mA; Fuse_1206_3216Metric
J1: USB_C Main; USB-C-12-Pin-MidMount
J2: USB_C I2C_L; USB-C-12-Pin-MidMount
J3: USB_C I2C_R; USB-C-12-Pin-MidMount
R1, R2: 5.1k; R_0402_HandSolder
R3, R4: 4.7k; R_0402_HandSolder
R5, R8, R9: 10k; R_0402_HandSolder
R6, R7: 22R; R_0402_HandSolder
SW1: SW_Push; Micro_Push_Button_3x6x2.5mm
SW2, SW3, SW4, SW5, SW6, SW7, SW8, SW9, SW10, SW11, SW12, SW13, SW14, SW15, SW16, SW18, SW19, SW20, SW21, SW22, SW23, SW24, SW25, SW26, SW27, SW28, SW29, SW30, SW31, SW32, SW34, SW35, SW36: SW_Push; Kailh_Choc_1u
SW17: Trackball_Choc_Combi; trackball_choc_combi
SW33, SW37: SW_Push; Kailh_Choc_1.5u
U1: ATmega32U4-AU; TQFP-44_10x10mm_P0.8mm
U2: PCA9555PW; TSSOP-24_4.4x7.8mm_P0.65mm
Y1: 16MHZ; Crystal_SMD_3225-4Pin_3.2x2.5mm

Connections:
+5V: C4.2, C5.2, C6.2, C7.2, C8.2, F1.2, J2.A4 (VBUS), J2.A9 (VBUS), J2.B4 (VBUS), J2.B9 (VBUS), R3.1, R4.1, R8.1, U1.2 (UVCC), U1.7 (VBUS), U1.14 (VCC), U1.24 (AVCC), U1.34 (VCC), U1.44 (AVCC)
/Col_L0: SW5.1, SW6.1, SW7.1, U1.11 (PB3)
/Col_L1: SW11.1, SW12.1, SW13.1, U1.1 (PE6)
/Col_L2: SW18.1, SW19.1, SW20.1, SW21.1, U1.36 (PF7)
/Col_L3: SW26.1, SW27.1, SW28.1, SW29.1, U1.30 (PB6)
/Col_L4: SW34.1, SW35.1, SW36.1, SW37.1, U1.29 (PB5)
/Col_R0: SW2.1, SW3.1, SW4.1, U2.4 (IO0_0)
/Col_R1: SW8.1, SW9.1, SW10.1, U2.5 (IO0_1)
/Col_R2: SW14.1, SW15.1, SW16.1, SW17.1, U2.6 (IO0_2)
/Col_R3: SW22.1, SW23.1, SW24.1, SW25.1, U2.7 (IO0_3)
/Col_R4: SW30.1, SW31.1, SW32.1, SW33.1, U2.8 (IO0_4)
/D+: R7.1, U1.4 (D+)
/D-: R6.1, U1.3 (D-)
/I2C_SCL_L: J2.A6 (D+), J2.B6 (D+), R4.2, U1.18 (PD0)
/I2C_SCL_R: J3.A6 (D+), J3.B6 (D+), SW17.SCL, U2.22 (SCL)
/I2C_SDA_L: J2.A7 (D-), J2.B7 (D-), R3.2, U1.19 (PD1)
/I2C_SDA_R: J3.A7 (D-), J3.B7 (D-), SW17.SDA, U2.23 (SDA)
/Row_L0: D5.1 (K), D11.1 (K), D18.1 (K), D26.1 (K), D34.1 (K), U1.8 (PB0)
/Row_L1: D6.1 (K), D12.1 (K), D19.1 (K), D27.1 (K), D35.1 (K), U1.9 (PB1)
/Row_L2: D7.1 (K), D13.1 (K), D20.1 (K), D28.1 (K), D36.1 (K), U1.10 (PB2)
/Row_L3: D21.1 (K), D29.1 (K), D37.1 (K), U1.28 (PB4)
/Row_R0: D2.1 (K), D8.1 (K), D14.1 (K), D22.1 (K), D30.1 (K), U2.13 (IO1_0)
/Row_R1: D3.1 (K), D9.1 (K), D15.1 (K), D23.1 (K), D31.1 (K), U2.14 (IO1_1)
/Row_R2: D4.1 (K), D10.1 (K), D16.1 (K), D24.1 (K), D32.1 (K), U2.15 (IO1_2)
/Row_R3: D17.1 (K), D25.1 (K), D33.1 (K), U2.16 (IO1_3)
GND: C1.2, C2.2, C4.1, C5.1, C6.1, C7.1, C8.1, C9.2, J1.A1 (GND), J1.A12 (GND), J1.B1 (GND), J1.B12 (GND), J2.A1 (GND), J2.A12 (GND), J2.B1 (GND), J2.B12 (GND), R1.2, R2.2, R9.1, SW1.1, U1.5 (UGND), U1.15 (GND), U1.23 (GND), U1.35 (GND), U1.43 (GND), Y1.2, Y1.4
unnamed: C1.1, U1.17 (XTAL1), Y1.1
unnamed: C2.1, U1.16 (XTAL2), Y1.3
unnamed: C9.1, U1.6 (UCAP)
unnamed: D2.2 (A), SW2.2
unnamed: D3.2 (A), SW3.2
unnamed: D4.2 (A), SW4.2
unnamed: D5.2 (A), SW5.2
unnamed: D6.2 (A), SW6.2
unnamed: D7.2 (A), SW7.2
unnamed: D8.2 (A), SW8.2
unnamed: D9.2 (A), SW9.2
unnamed: D10.2 (A), SW10.2
unnamed: D11.2 (A), SW11.2
unnamed: D12.2 (A), SW12.2
unnamed: D13.2 (A), SW13.2
unnamed: D14.2 (A), SW14.2
unnamed: D15.2 (A), SW15.2
unnamed: D16.2 (A), SW16.2
unnamed: D17.2 (A), SW17.2
unnamed: D18.2 (A), SW18.2
unnamed: D19.2 (A), SW19.2
unnamed: D20.2 (A), SW20.2
unnamed: D21.2 (A), SW21.2
unnamed: D22.2 (A), SW22.2
unnamed: D23.2 (A), SW23.2
unnamed: D24.2 (A), SW24.2
unnamed: D25.2 (A), SW25.2
unnamed: D26.2 (A), SW26.2
unnamed: D27.2 (A), SW27.2
unnamed: D28.2 (A), SW28.2
unnamed: D29.2 (A), SW29.2
unnamed: D30.2 (A), SW30.2
unnamed: D31.2 (A), SW31.2
unnamed: D32.2 (A), SW32.2
unnamed: D33.2 (A), SW33.2
unnamed: D34.2 (A), SW34.2
unnamed: D35.2 (A), SW35.2
unnamed: D36.2 (A), SW36.2
unnamed: D37.2 (A), SW37.2
unnamed: F1.1, J1.A4 (VBUS), J1.A9 (VBUS), J1.B4 (VBUS), J1.B9 (VBUS)
unnamed: J1.A5 (CC1), R1.1
unnamed: J1.A6 (D+), J1.B6 (D+), R7.2
unnamed: J1.A7 (D-), J1.B7 (D-), R6.2
unnamed: J1.B5 (CC2), R2.1
unnamed: R5.2, U2.1 (~INT)
unnamed: R8.2, SW1.2, U1.13 (~RESET)
unnamed: R9.2, U1.33 (~HWB~/PE2)
VDD: C3.2, J3.A4 (VBUS), J3.A9 (VBUS), J3.B4 (VBUS), J3.B9 (VBUS), R5.1, SW17.VCC, U2.24 (VDD)
VSS: C3.1, J3.A1 (GND), J3.A12 (GND), J3.B1 (GND), J3.B12 (GND), SW17.GND, U2.2 (A1), U2.3 (A2), U2.12 (VSS), U2.21 (A0)

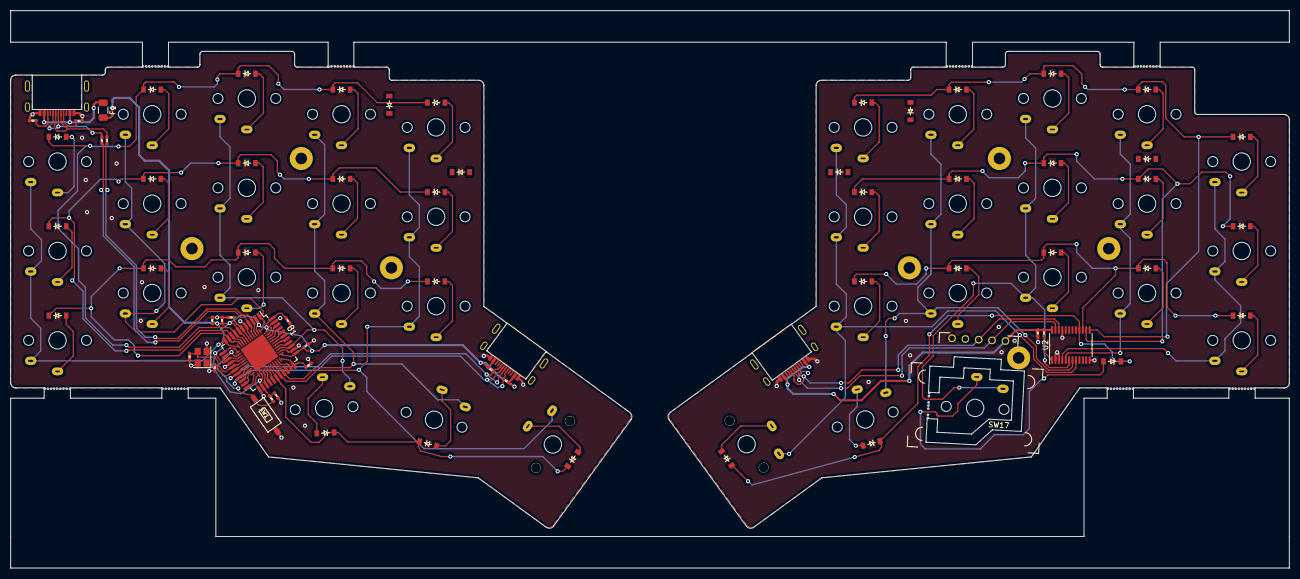
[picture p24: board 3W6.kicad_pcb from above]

Board: 2 copper layers, 243.2 x 106.0 mm, 103 parts (0 on the bottom side), 75 nets.

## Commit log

2021-03-18 add: parametric Freecad-Model for the plate/outline
    [Outline.FCStd]
2021-03-20 Add: DXF Board Outlines
    [Outline_v1.dxf, Outline_v1_R.dxf]
2021-03-20 Add: USB connector data sheet
2021-03-20 Add: KiCad Files + First Schematic
    [WetCorn.kicad_pcb, WetCorn.sch]
2021-03-21 outline.dxf for left/right pcb
    [OutlinePlate_v1.dxf, Outline_v1.dxf]
2021-03-21 pcb wip
    [WetCorn.kicad_pcb]
2021-03-21 clean up outline files
    [Outline_v1_R.dxf]
2021-03-22 PCB finished
    [WetCorn.kicad_pcb, WetCorn.sch]
2021-03-23 Add: Plate PCB
    [3W6_Plate.kicad_pcb]
2021-06-08 fixing some outlines
    [3W6.kicad_pcb, 3W6.sch, 3W6_Plate.kicad_pcb]
2021-06-08 add production files (bom might not be valid)
    [20210329_3W6_BOM.csv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]
2021-06-15 add finished board
2021-06-15 change size of board image
2021-06-20 add outline file for switchplate
2021-06-21 new pcb file structure
    [3W6.kicad_pcb, 3W6.sch, 3W6_Plate.kicad_pcb]
2021-06-21 fix library paths to use included part library fix wrong value for crystal condensators
    [3W6.kicad_pcb, 3W6.sch]
2021-06-28 add footprint for pimoroni trackball
2021-06-29 add: symbol and footprint for trackball/switch combination
2021-06-29 add: Pimoroni Trackball support
    [3W6.kicad_pcb, 3W6.sch]
2021-06-29 chg: plate to match pcb after trackball support
    [3W6_Plate.kicad_pcb]
2021-06-29 chg: uses atmega32u4-AU now
    [3W6.kicad_pcb, 3W6.sch]
2021-06-30 add: middle plate chg: rerouting whole board, to eliminate traces under middle plate chg: repositioning components to get a higher clearance in case an aluminium or steel middle plate is used.
    [3W6.kicad_pcb, 3W6.sch, 3W6_Plate.kicad_pcb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]
2021-07-01 fix middle plate outlines right half
    [3W6_middle.kicad_pcb]
2021-07-01 chg: new io-expander (TCA9535), change package to TSSOP-24
    [3W6.kicad_pcb]
2021-07-04 making files ready for production
    [3W6.kicad_pcb, 3W6.sch, 3W6_Plate.kicad_pcb]
2021-07-04 adding single files for alu middle plate sides
    [3W6_middle_single_L.kicad_pcb, 3W6_middle_single_R.kicad_pcb]
2021-07-09 changes for production
    [3W6.kicad_pcb, 3W6_Plate.kicad_pcb, 3W6_middle.kicad_pcb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]
2021-07-09 update production files
    [20210329_3W6_BOM.csv, 3W6_Pcb_BOM_20210705.csv, 3W6_Pcb_PositionTop_20210705.csv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]
2021-07-28 fix problems from last production run
    changed IO-Expander to PCA9555
    moved some vias to connect the copper island around the pimoroni GND pin to board GND
    [3W6.kicad_pcb, 3W6.sch]
2021-07-28 adding corrected production files
    [3W6_Pcb_BOM_20210705.csv, 3W6_Pcb_BOM_20210728.csv, 3W6_Pcb_PositionTop_20210705.csv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]
2021-07-28 increased version no to 2.1 to distinguish boards from different runs/changes
    [3W6.kicad_pcb, 3W6.sch]
2021-08-19 add 3d printing files by bomtarnes
    [3W6_Plate-left-v2.stl, 3W6_Plate-middle-left-v2.stl, 3W6_Plate-middle-right-v2.stl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]
2022-10-18 add combie footprint for atmega. Can be used with MU and AU variant
    [3W6.kicad_pcb]
2022-10-18 Add updated production files
    [3W6_Pcb_BOM_20210728.csv, 3W6_Pcb_BOM_AU_20221018.csv, 3W6_Pcb_BOM_MU_20221018.csv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]

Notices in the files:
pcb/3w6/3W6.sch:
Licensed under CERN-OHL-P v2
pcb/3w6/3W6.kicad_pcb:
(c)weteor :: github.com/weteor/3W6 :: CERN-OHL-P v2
